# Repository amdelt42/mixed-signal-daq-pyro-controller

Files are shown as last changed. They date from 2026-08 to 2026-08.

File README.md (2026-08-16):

# Mixed-Signal DAQ & Pyrotechnic Control System

This repository contains the [firmware / hardware design] for an STM32-powered data acquisition board.

## Key Features

* **Microcontroller:** STM32 core managing real-time loops, sensor aggregation, and firing logic.
* **Analog Front End:** 
  * Full-bridge strain gauge and Thermocouple measurement signal blocks with dedicated filtering.
  * Local digital temperature sensor for real-time Cold-Junction Compensation (CJC).
  * High-resolution Analog-to-Digital Converter (ADC).
* **Actuation:** Integrated pyrotechnic firing channels.
* **Telemetry & Comms:** High bit-rate CAN FD transceiver for high-bandwidth data output.

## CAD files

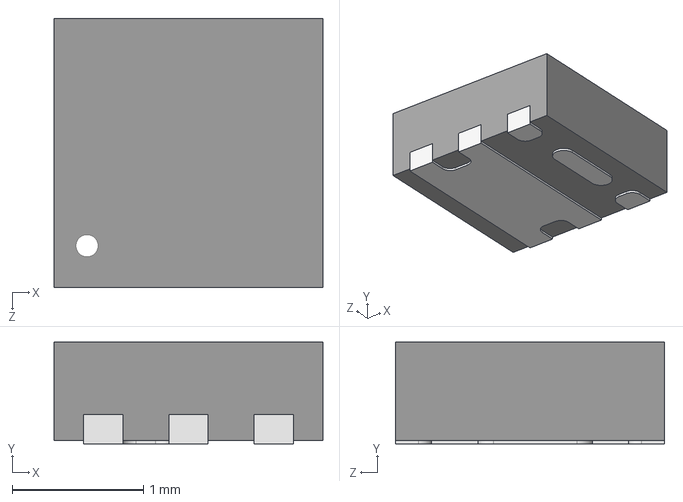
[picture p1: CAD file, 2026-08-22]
GENERAL_STEP_FILES/SQA405EJ-T1_GE3.step
2.05 x 0.775 x 2.05 mm

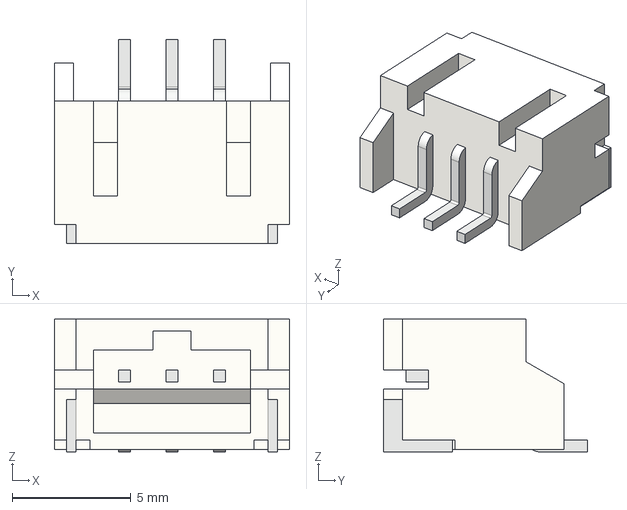
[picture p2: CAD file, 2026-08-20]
JST_PH_SM4_STEP_FILES/JST S3B-PH-SM4-TB.step
9.90 x 8.61 x 5.60 mm

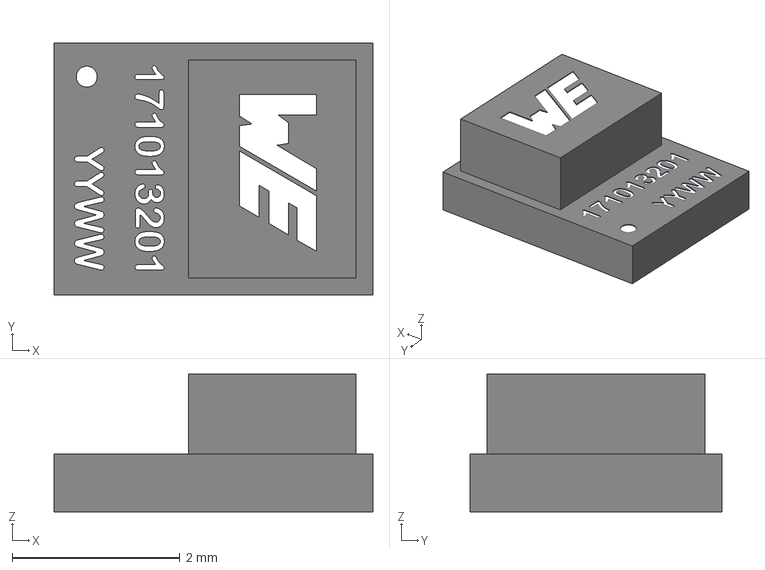
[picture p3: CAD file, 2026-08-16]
MagI3C_171013201/STP_MagIC-VDMM_171013201+(rev1).stp
3.80 x 3.00 x 1.64 mm
contacts
substrate x 2

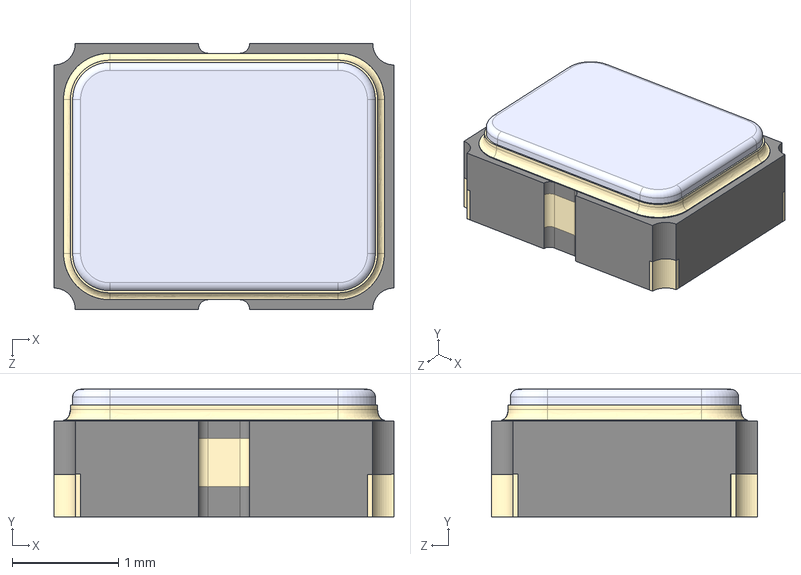
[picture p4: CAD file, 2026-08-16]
SG-8018CE_8.9152M-TJHSA0/SG-8018CE_8.9152M-TJHSA0.step
3.20 x 1.20 x 2.50 mm

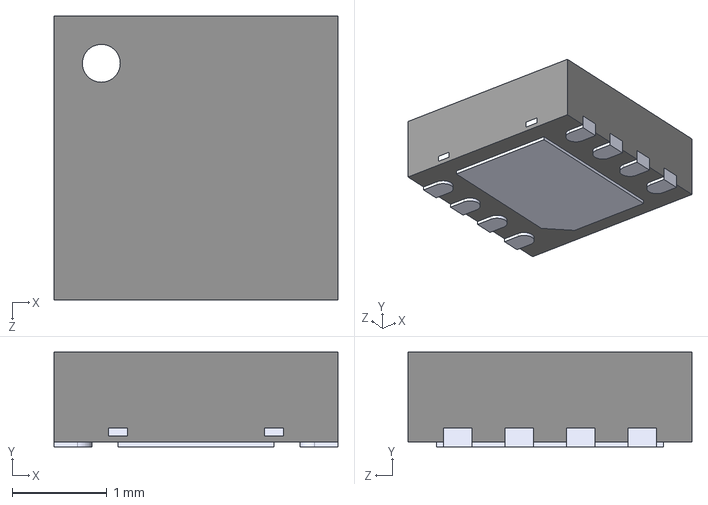
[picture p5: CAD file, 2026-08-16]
TCAN3414DRBR/TCAN3414DRBR.step
3.00 x 1.00 x 3.00 mm

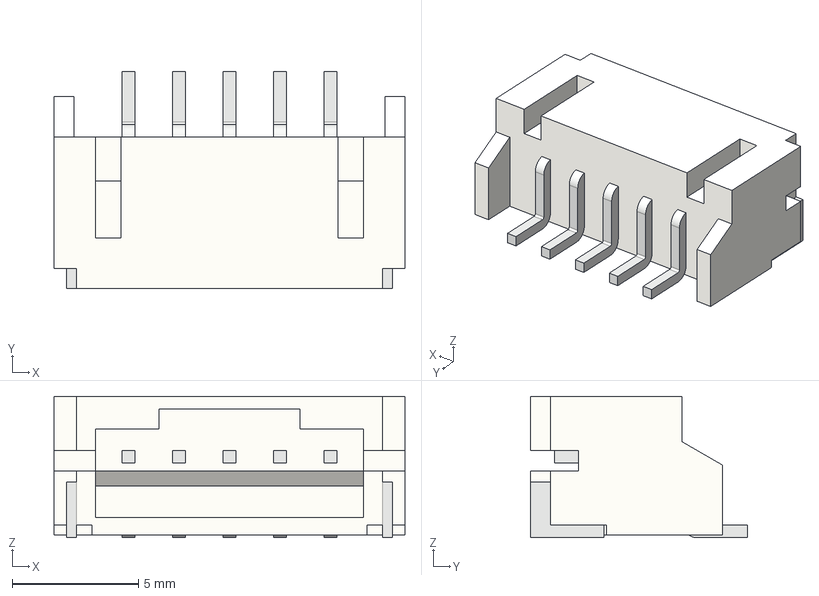
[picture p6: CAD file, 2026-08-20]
JST_PH_SM4_STEP_FILES/JST S5B-PH-SM4-TB.step
13.9 x 8.61 x 5.60 mm

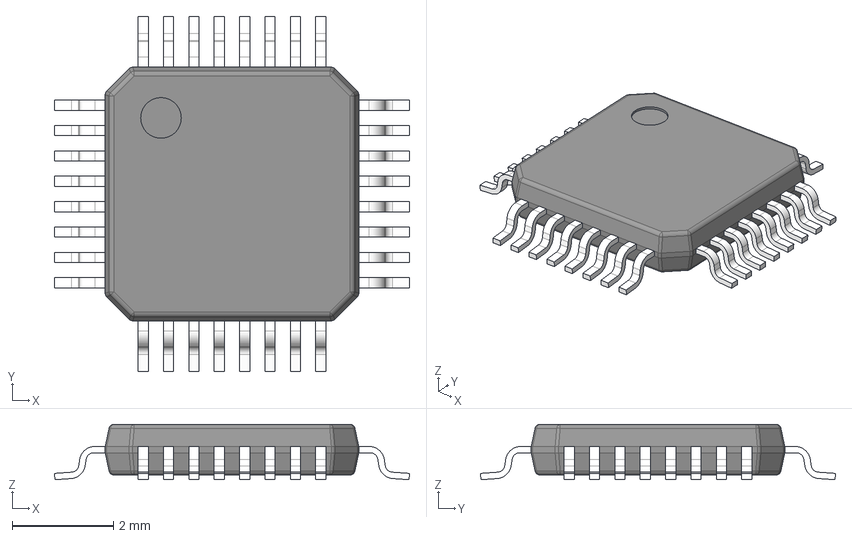
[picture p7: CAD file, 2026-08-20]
GENERAL_STEP_FILES/ADS131M08xPBS.stp
7.00 x 7.00 x 1.09 mm
BODY-TQFP
LEAD-TQFP x 32
PIN1

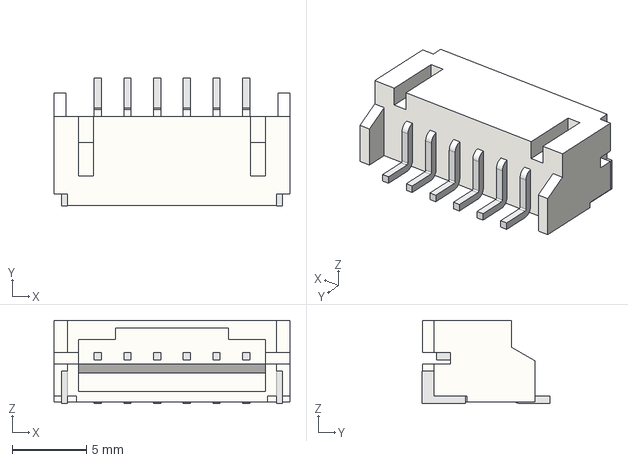
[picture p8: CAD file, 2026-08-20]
JST_PH_SM4_STEP_FILES/JST S6B-PH-SM4-TB.step
15.9 x 8.61 x 5.60 mm

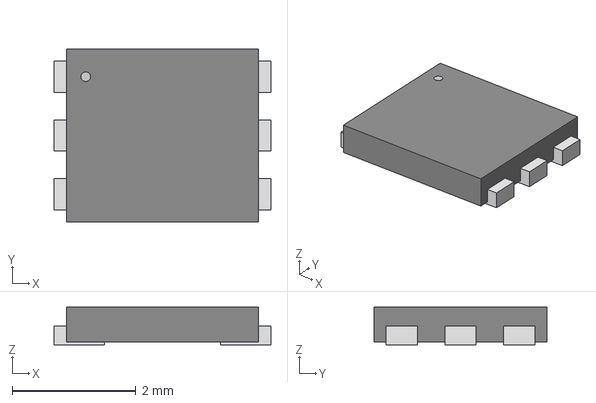
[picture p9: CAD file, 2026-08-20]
GENERAL_STEP_FILES/SMLVN6RGB.step
3.51 x 2.79 x 0.612 mm

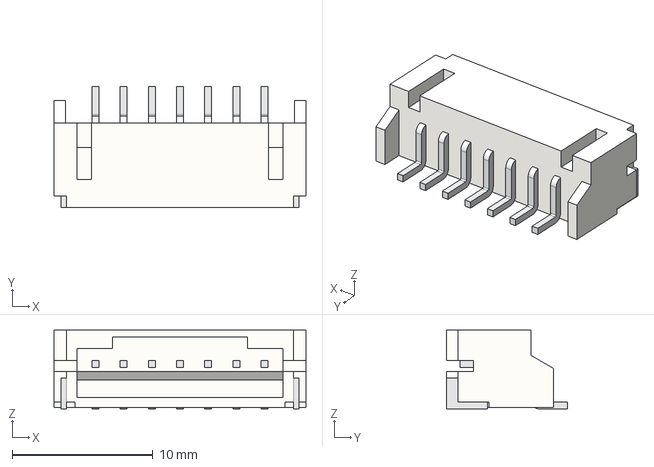
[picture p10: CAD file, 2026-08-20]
JST_PH_SM4_STEP_FILES/JST S7B-PH-SM4-TB.step
17.9 x 8.61 x 5.60 mm

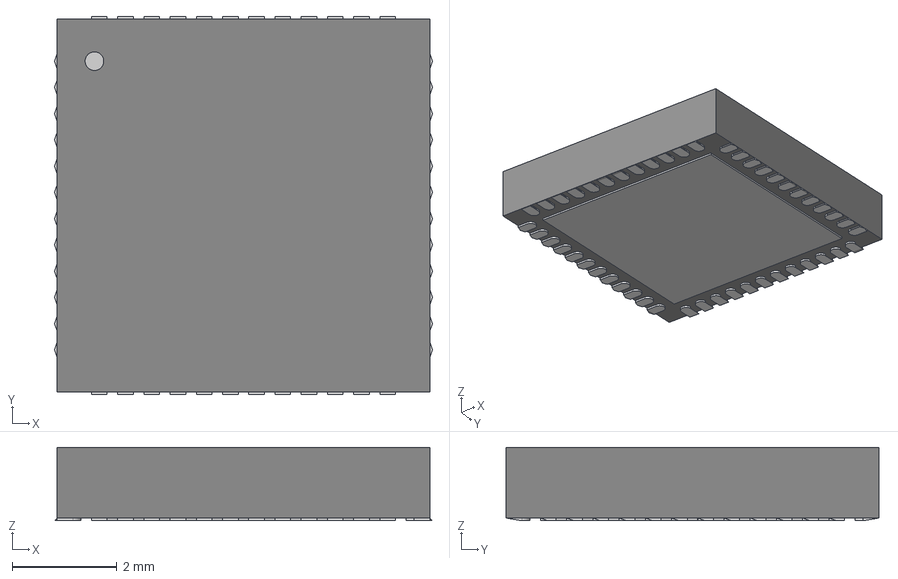
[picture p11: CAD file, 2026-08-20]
GENERAL_STEP_FILES/STM32L552CEUx.step
7.20 x 7.20 x 1.40 mm

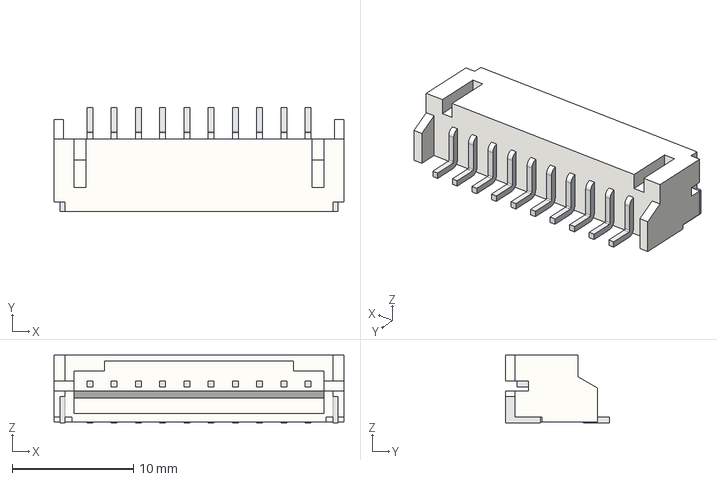
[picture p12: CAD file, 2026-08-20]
JST_PH_SM4_STEP_FILES/JST S10B-PH-SM4-TB.step
23.9 x 8.61 x 5.60 mm

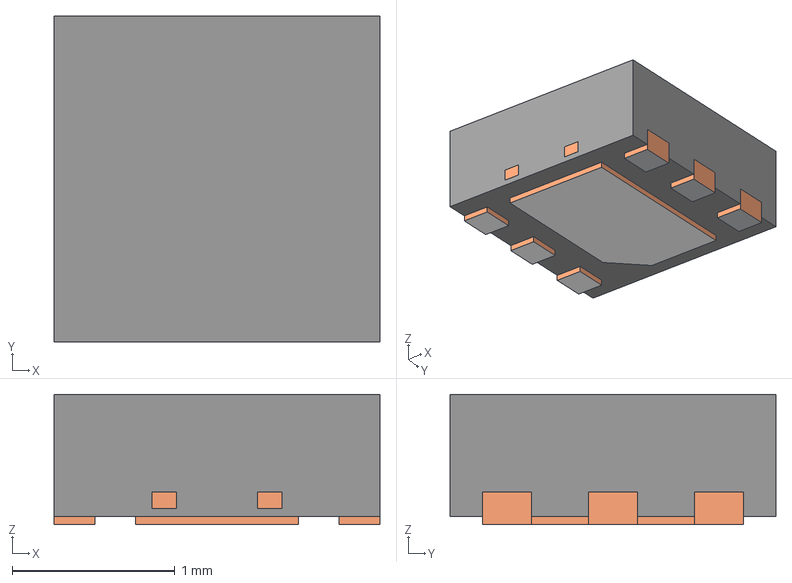
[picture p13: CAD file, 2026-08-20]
GENERAL_STEP_FILES/TMP117xxDRV.stp
2.00 x 2.00 x 0.8 mm
BODY-SON
FRAME-DRV0006A
PIN1-ID

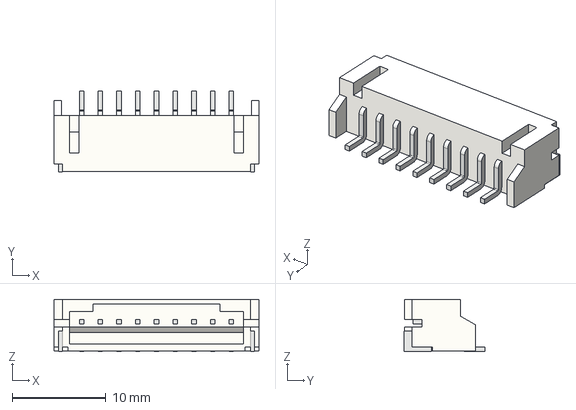
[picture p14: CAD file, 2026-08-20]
JST_PH_SM4_STEP_FILES/JST S9B-PH-SM4-TB.step
21.9 x 8.61 x 5.60 mm

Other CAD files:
JST_PH_SM4_STEP_FILES/JST S4B-PH-SM4-TB.step
JST_PH_SM4_STEP_FILES/JST S2B-PH-SM4-TB.step
JST_PH_SM4_STEP_FILES/JST S8B-PH-SM4-TB.step
GENERAL_STEP_FILES/LM27762.stp

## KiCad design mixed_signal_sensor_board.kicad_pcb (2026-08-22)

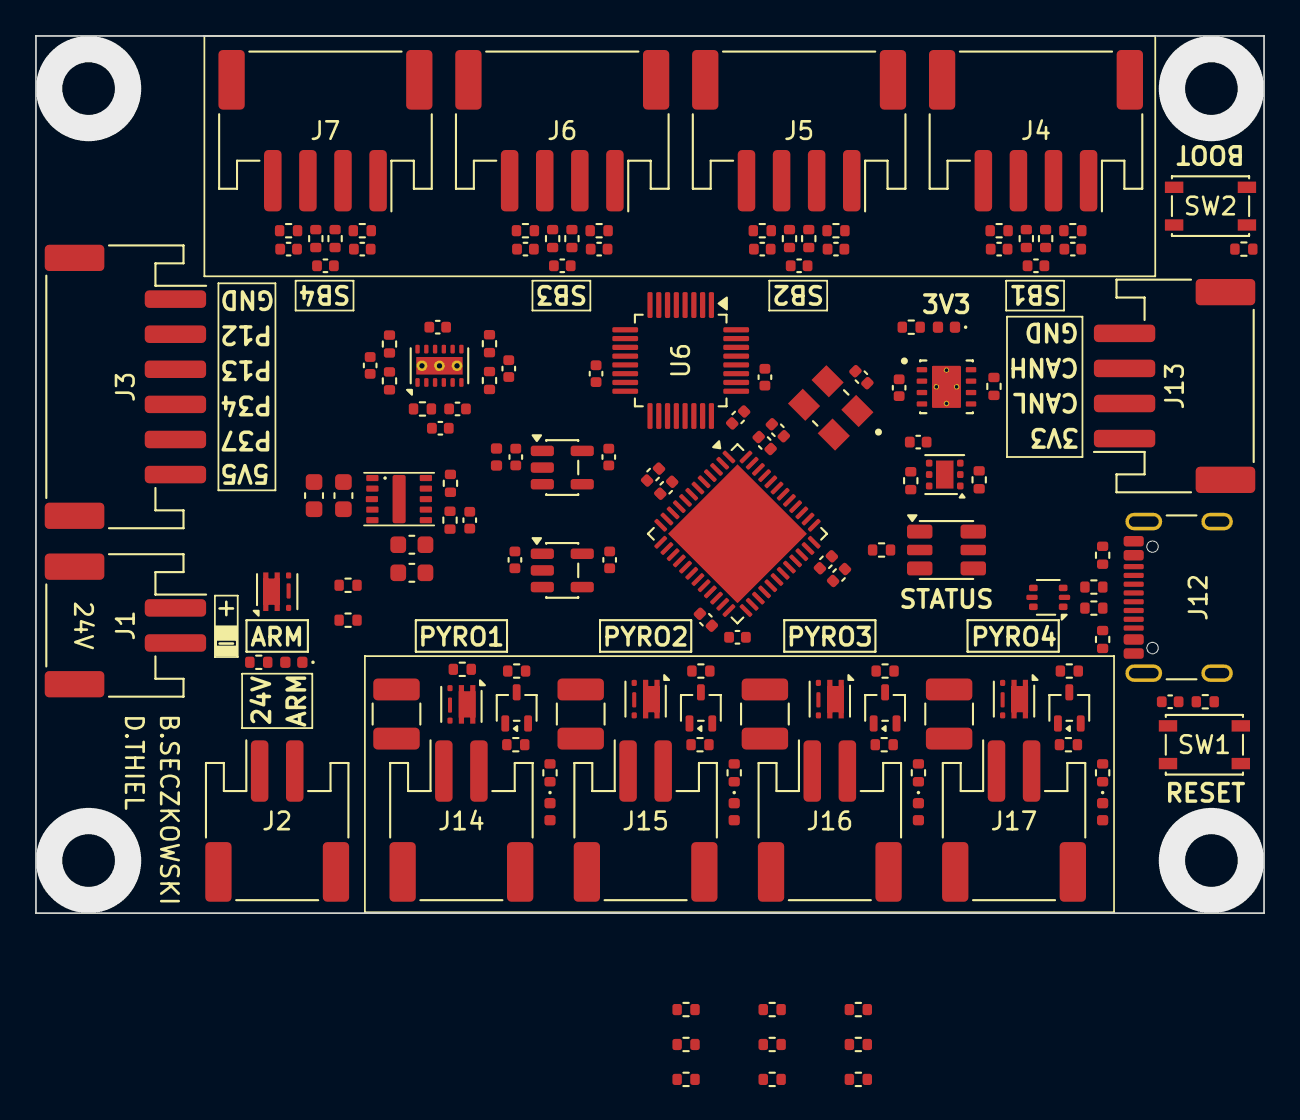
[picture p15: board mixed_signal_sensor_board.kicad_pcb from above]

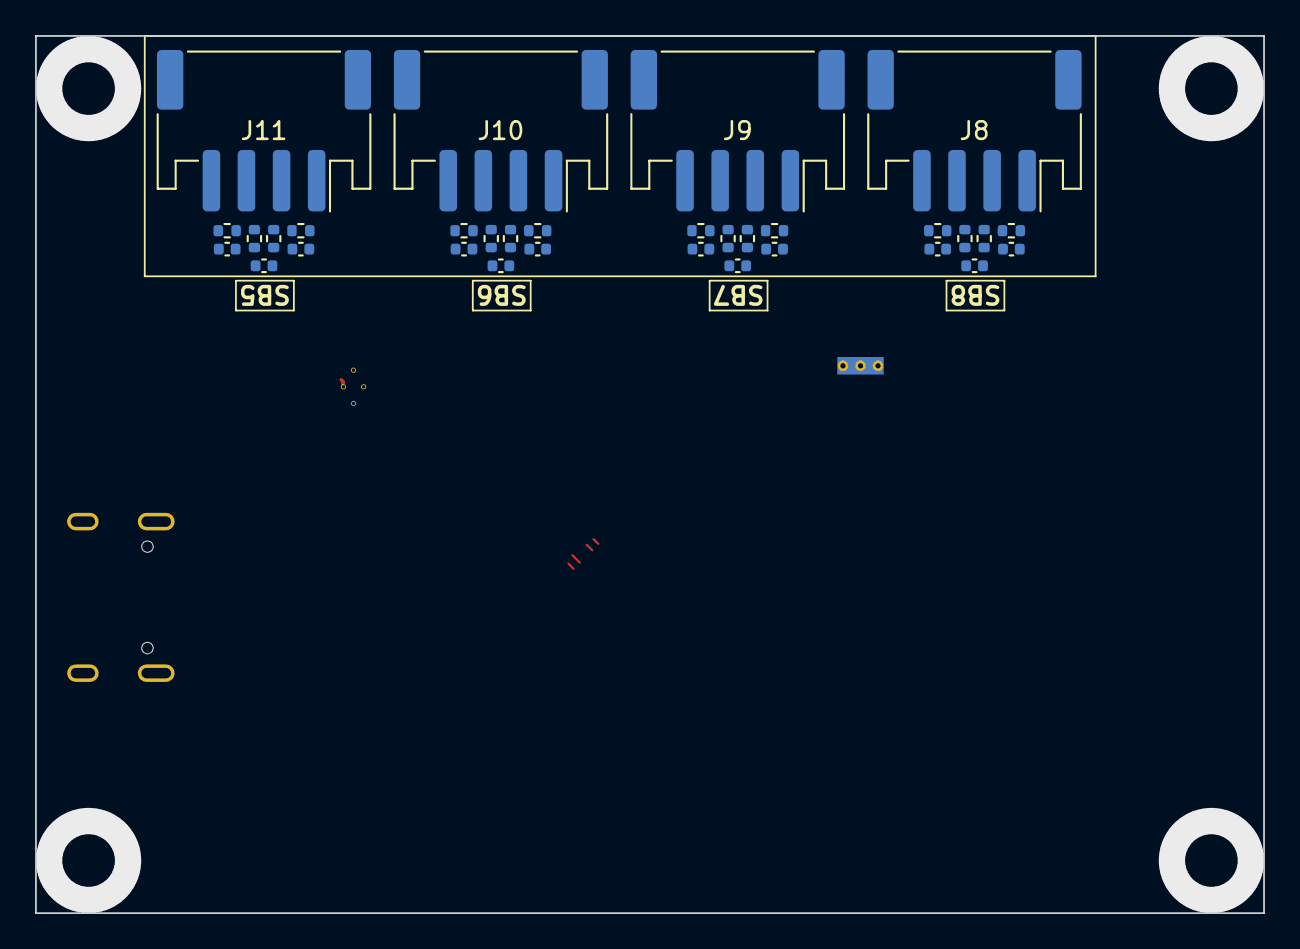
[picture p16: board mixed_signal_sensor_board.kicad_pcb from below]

Board: 4 copper layers, 70.0 x 50.0 mm, 178 parts (32 on the bottom side), 111 nets.

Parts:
C1: 4.7uF; C_0603_1608Metric
C2, C6, C21, C22, C23: 4.7uF; C_0402_1005Metric
C3: 0.47uF; C_0402_1005Metric
C4: 0.47uF; C_0603_1608Metric
C5, C14, C18, C19, C20, C28, C30, C31, C33, C34, C36, C37, C39, C40, C42, C43, C45, C46, C48, C49, C51, C52, C53: 0.1uF; C_0402_1005Metric
C7, C8: 10uF; C_0603_1608Metric
C9, C11: 2.2uF; C_0402_1005Metric
C10: 47pf; C_0402_1005Metric
C12, C13, C15, C16, C17, C24, C26: 1uF; C_0402_1005Metric
C25: 0.22uF; C_0402_1005Metric
C27: 10nF; C_0402_1005Metric
C29, C32, C35, C38, C41, C44, C47, C50: 10nf; C_0402_1005Metric
D1: 24V; D_0402_1005Metric
D2: SMLVN6RGB; LED_ROHM_SMLVN6
D3: LED; LED_0402_1005Metric
D4, D5, D6, D7: 3V; D_0402_1005Metric
F1, F2, F3, F4: MF-USHT050KX-2; Fuse_1210_3225Metric
FB1: 600Ω@100MHz; L_0402_1005Metric
J1: Conn_01x02; JST_PH_S2B-PH-SM4-TB_1x02-1MP_P2.00mm_Horizontal
J2: PYRO_ARM; JST_PH_S2B-PH-SM4-TB_1x02-1MP_P2.00mm_Horizontal
J3: Conn_01x06; JST_PH_S6B-PH-SM4-TB_1x06-1MP_P2.00mm_Horizontal
J4, J5, J6, J7, J8, J9, J10, J11, J13: Conn_01x04; JST_PH_S4B-PH-SM4-TB_1x04-1MP_P2.00mm_Horizontal
J12: USB_C_Receptacle_USB2.0_16P; USB_C_Receptacle_GCT_USB4105-xx-A_16P_TopMnt_Horizontal
J14, J15, J16, J17: PYRO; JST_PH_S2B-PH-SM4-TB_1x02-1MP_P2.00mm_Horizontal
Q2, Q4, Q6, Q8: 2N7002WT1G; SOT-323_SC-70
Q3, Q5, Q7, Q9, Q10: SQA405EJ-T1_GE3; Vishay_PowerPAK_SC70-6L_Single
R1, R5, R6, R9, R10, R17, R18, R21, R22, R25, R26, R29, R30, R33, R34, R37, R38, R41, R42, R45, R46: 10K; R_0402_1005Metric
R2, R7: 100K; R_0402_1005Metric
R3, R4: 5K; R_0402_1005Metric
R8: 16K9; R_0402_1005Metric
R11, R14, R51: 120R; R_0402_1005Metric
R12, R13: 4K7; R_0402_1005Metric
R15, R16, R19, R20, R23, R24, R27, R28, R31, R32, R35, R36, R39, R40, R43, R44: 1MΩ; R_0402_1005Metric
R47, R48: 5K1; R_0402_1005Metric
R49, R50: 22R; R_0402_1005Metric
R52, R54, R58, R60, R64, R66, R70, R72: 10k; R_0402_1005Metric
R53, R55, R59, R61, R65, R67, R71, R73: 1k; R_0402_1005Metric
R56, R57, R62, R63, R68, R69, R74, R75: 50k; R_0402_1005Metric
SW1, SW2: SW_Push; SW_SPST_PTS810
U1: TMP117xxDRV; WSON-6-1EP_2x2mm_P0.65mm_EP1x1.6mm
U2: LM27762; WSON-12-1EP_3x2mm_P0.5mm_EP1x2.65_ThermalVias
U3: MagI3C_171013201
U4, U5: TPS7A20xxxDBV; SOT-23-5
U6: ADS131M08xPBS; TQFP-32_5x5mm_P0.5mm
U7: STM32L552CEUx; QFN-48-1EP_7x7mm_P0.5mm_EP5.6x5.6mm
U8: USBLC6-2P6; SOT-666
U9: TCAN3414DRBR; XCVR_TCAN3414DRBR
Y1: SG-8018CE_8.192M-TJHSA; OSC_SG-8018CE_8.9152M-TJHSA0

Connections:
+3V3: C5.1, C16.1, C18.2, C19.2, C20.2, C21.2, C22.2, C23.2, C24.1, C28.2, C53.1, J13.1, R3.2, R4.2, R12.1, R14.1, SW2.1, U1.5 (V+), U5.5 (OUT), U6.26 (DVDD), U7.1 (VBAT), U7.24 (VDD), U7.36 (VDD), U7.48 (VDD), U9.3 (VCC), Y1.1 (~ST), Y1.4 (VCC)
+3V3A: C15.1, C17.1, C26.2, C27.2, R15.1, R19.1, R23.1, R27.1, R31.1, R35.1, R39.1, R43.1, U4.5 (OUT), U6.15 (AVDD), U7.9 (VDDA)
+5V: C9.1, J4.1, J5.1, J6.1, J7.1, J8.1, J9.1, J10.1, J11.1, R5.1, U2.11 (OUT+)
+5V5: C2.2, C7.2, C8.2, C10.2, C13.2, FB1.2, J3.6, R1.1, R7.1, U2.3 (VIN), U2.8 (EN-), U2.12 (EN+), U3.6 (VOUT), U5.1 (IN), U5.3 (EN)
+24V: C1.2, C4.2, D1.1 (K), J2.1, Q10.4 (S), R56.2, R62.2, R68.2, R74.2, U3.3 (VIN), U3.4 (EN)
-5V: C11.1, J4.4, J5.4, J6.4, J7.4, J8.4, J9.4, J10.4, J11.4, R9.1, U2.6 (OUT-)
/ADS_DRDY: U6.18 (~DRDY), U7.2 (PC13)
/ADS_SYNC/RESET: U6.16 (~SYNC/~RESET), U7.3 (PC14)
/BOOT0: R13.1, SW2.2, U7.44 (PH3)
/CAN/CAN_H: J13.3, R51.2, U9.7 (CANH)
/CAN/CAN_L: J13.2, R51.1, U9.6 (CANL)
/CAN_RX: U7.45 (PB8), U9.4 (RXD)
/CAN_TX: U7.46 (PB9), U9.1 (TXD)
/CLK_IN: U6.23 (XTAL1/CLKIN), Y1.3 (OUT)
/CS: U6.17 (~CS), U7.14 (PA4)
/FB: C10.1, R7.2, R8.1, U3.7 (FB)
/FB+: R5.2, R6.1, U2.2 (FB+)
/FB-: R9.2, R10.1, U2.7 (FB-)
/LEDB: D2.1 (BA), U7.41 (PB5)
/LEDG: D2.3 (GA), U7.39 (PB3)
/LEDR: R11.1, U7.40 (PB4)
/MISO: U6.20 (DOUT), U7.16 (PA6)
/MOSI: U6.21 (DIN), U7.17 (PA7)
/NRST: C14.1, R12.2, SW1.2, U7.7 (NRST)
/PGOOD: R1.2, U2.1 (PGOOD), U7.38 (PA15)
/PYRO1_FAULT: D4.1 (K), R57.2, U7.19 (PB1)
/PYRO1_SIGNAL: R52.2, R53.1, U7.18 (PB0)
/PYRO2_FAULT: D5.1 (K), R63.2, U7.21 (PB10)
/PYRO2_SIGNAL: R58.2, R59.1, U7.20 (PB2)
/PYRO3_FAULT: D6.1 (K), R69.2, U7.28 (PB15)
/PYRO3_SIGNAL: R64.2, R65.1, U7.29 (PA8)
/PYRO4_FAULT: D7.1 (K), R75.2, U7.30 (PA9)
/PYRO4_SIGNAL: R70.2, R71.1, U7.31 (PA10)
/SB1/AOUT_N: C29.2, C31.2, R18.2, U6.2 (AIN2N)
/SB1/AOUT_P: C29.1, C30.1, R17.2, U6.1 (AIN2P)
/SB1/SIGNAL_N: J4.3, R16.1, R18.1
/SB1/SIGNAL_P: J4.2, R15.2, R17.1
/SB2/AOUT_N: C32.2, C34.2, R22.2, U6.3 (AIN3N)
/SB2/AOUT_P: C32.1, C33.1, R21.2, U6.4 (AIN3P)
/SB2/SIGNAL_N: J5.3, R20.1, R22.1
/SB2/SIGNAL_P: J5.2, R19.2, R21.1
/SB3/AOUT_N: C35.2, C37.2, R26.2, U6.6 (AIN4N)
/SB3/AOUT_P: C35.1, C36.1, R25.2, U6.5 (AIN4P)
/SB3/SIGNAL_N: J6.3, R24.1, R26.1
/SB3/SIGNAL_P: J6.2, R23.2, R25.1
/SB4/AOUT_N: C38.2, C40.2, R30.2, U6.7 (AIN5N)
/SB4/AOUT_P: C38.1, C39.1, R29.2, U6.8 (AIN5P)
/SB4/SIGNAL_N: J7.3, R28.1, R30.1
/SB4/SIGNAL_P: J7.2, R27.2, R29.1
/SB5/AOUT_N: C41.2, C43.2, R34.2, U6.11 (AIN7N)
/SB5/AOUT_P: C41.1, C42.1, R33.2, U6.12 (AIN7P)
/SB5/SIGNAL_N: J8.3, R32.1, R34.1
/SB5/SIGNAL_P: J8.2, R31.2, R33.1
/SB6/AOUT_N: C44.2, C46.2, R38.2, U6.10 (AIN6N)
/SB6/AOUT_P: C44.1, C45.1, R37.2, U6.9 (AIN6P)
/SB6/SIGNAL_N: J9.3, R36.1, R38.1
/SB6/SIGNAL_P: J9.2, R35.2, R37.1
/SB7/AOUT_N: C47.2, C49.2, R42.2, U6.31 (AIN1N)
/SB7/AOUT_P: C47.1, C48.1, R41.2, U6.32 (AIN1P)
/SB7/SIGNAL_N: J10.3, R40.1, R42.1
/SB7/SIGNAL_P: J10.2, R39.2, R41.1
/SB8/AOUT_N: C50.2, C52.2, R46.2, U6.30 (AIN0N)
/SB8/AOUT_P: C50.1, C51.1, R45.2, U6.29 (AIN0P)
/SB8/SIGNAL_N: J11.3, R44.1, R46.1
/SB8/SIGNAL_P: J11.2, R43.2, R45.1
/SCL: R4.1, U1.1 (SCL), U7.42 (PB6)
/SCLK: U6.19 (SCLK), U7.15 (PA5)
/SDA: R3.1, U1.6 (SDA), U7.43 (PB7)
/SWCLK: J3.5, U7.37 (PA14)
/SWDIO: J3.4, U7.34 (PA13)
/USART2_RX: J3.3, U7.13 (PA3)
/USART2_TX: J3.2, U7.12 (PA2)
/USB/DN: J12.A7 (D-), J12.B7 (D-), R49.1
/USB/DP: J12.A6 (D+), J12.B6 (D+), R50.1
/USB_N: U7.32 (PA11), U8.6 (I/O1)
/USB_P: U7.33 (PA12), U8.4 (I/O2)
ARM: J2.2, Q3.1 (D), Q5.1 (D), Q7.1 (D), Q9.1 (D), R54.1, R60.1, R66.1, R72.1
GND: C1.1, C2.1, C4.1, C5.2, C6.2, C7.1, C8.1, C9.2, C11.2, C12.1, C13.1, C14.2, C15.2, C16.2, C17.2, C18.1, C19.1, C20.1, C21.1, C22.1, C23.1, C24.2, C25.2, C26.1, C27.1, C28.1, C30.2, C31.1, C33.2, C34.1, C36.2, C37.1, C39.2, C40.1, C42.2, C43.1, C45.2, C46.1, C48.2, C49.1, C51.2, C52.1, C53.2, D2.4 (GK), D2.5 (RK), D2.6 (BK), D3.1 (K), D4.2 (A), D5.2 (A), D6.2 (A), D7.2 (A), J1.2, J3.1, J12.A1 (GND), J12.A12 (GND), J12.B1 (GND), J12.B12 (GND), J13.4, J14.2, J15.2, J16.2, J17.2, Q2.2 (S), Q4.2 (S), Q6.2 (S), Q8.2 (S), R2.2, R6.2, R8.2, R10.2, R13.2, R16.2, R20.2, R24.2, R28.2, R32.2, R36.2, R40.2, R44.2, R47.1, R48.1, R52.1, R58.1, R64.1, R70.1, SW1.1, U1.2 (GND), U1.4 (ADD0), U2.4 (GND), U2.13 (PAD), U3.1 (GND), U4.2 (GND), U5.2 (GND), U6.13 (AGND), U6.25 (DGND), U6.27 (AGND), U6.28 (AGND), U7.8 (VSSA), U7.23 (VSS), U7.35 (VSS), U7.47 (VSS), U7.49 (VSS), U8.2 (GND), U9.2 (GND), U9.5 (SHDN), U9.8 (STB), U9.9 (EXP), Y1.2 (GND)
unnamed: D1.2 (A), Q10.3 (G), R2.1
unnamed: D2.2 (RA), R11.2
unnamed: D3.2 (A), R14.2
unnamed: J1.1, Q10.1 (D)
unnamed: J12.A5 (CC1), R48.2
unnamed: J12.B5 (CC2), R47.2
unnamed: F1.2, J14.1, R56.1, R57.1
unnamed: F2.2, J15.1, R62.1, R63.1
unnamed: F3.2, J16.1, R68.1, R69.1
unnamed: F4.2, J17.1, R74.1, R75.1
unnamed: Q2.3 (D), R54.2, R55.1
unnamed: Q2.1 (G), R53.2
unnamed: Q3.3 (G), R55.2
unnamed: F1.1, Q3.4 (S)
unnamed: Q4.3 (D), R60.2, R61.1
unnamed: Q4.1 (G), R59.2
unnamed: Q5.3 (G), R61.2
unnamed: F2.1, Q5.4 (S)
unnamed: Q6.3 (D), R66.2, R67.1
unnamed: Q6.1 (G), R65.2
unnamed: Q7.3 (G), R67.2
unnamed: F3.1, Q7.4 (S)
unnamed: Q8.3 (D), R72.2, R73.1
unnamed: Q8.1 (G), R71.2
unnamed: Q9.3 (G), R73.2
unnamed: F4.1, Q9.4 (S)
unnamed: R49.2, U8.1 (I/O1)
unnamed: R50.2, U8.3 (I/O2)
unnamed: C3.1, U2.10 (C+)
unnamed: C3.2, U2.9 (C-)
unnamed: C6.1, U2.5 (CP)
unnamed: C12.2, FB1.1, U4.1 (IN), U4.3 (EN)
unnamed: C25.1, U6.24 (CAP)

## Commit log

2026-08-19 24V Regulator, Pyro Igniter Circuit
    [can.kicad_sch, mixed_signal_sensor_board.kicad_pcb, mixed_signal_sensor_board.kicad_sch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]
2026-08-20 Pyro fault detection, Decoupling Caps STM32, Initial PCB Layout
    [can.kicad_sch, mixed_signal_sensor_board.kicad_pcb, mixed_signal_sensor_board.kicad_sch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]
2026-08-20 Finished first rough initial layout
    [mixed_signal_sensor_board.kicad_pcb, mixed_signal_sensor_board.kicad_sch]
2026-08-20 Step files, SMD connectors, reduced size
    [ADS131M08xPBS.stp, CSD17571Q2.stp, JST S10B-PH-SM4-TB.step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]
2026-08-20 Delvin protection, USB ESD protection, 02x06 pin socket
    [can.kicad_sch, mixed_signal_sensor_board.kicad_pcb, mixed_signal_sensor_board.kicad_sch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]
2026-08-21 replaced signal blocks, shortening board, adding precise positioning
    [can.kicad_sch, mixed_signal_sensor_board.kicad_pcb, mixed_signal_sensor_board.kicad_sch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]
2026-08-21 Compact board, Artistic Freedom
    [mixed_signal_sensor_board.kicad_pcb, mixed_signal_sensor_board.kicad_sch]
2026-08-21 Artistic Freedom
    [mixed_signal_sensor_board.kicad_pcb]
2026-08-21 removed SPI, I2C, compacting pyro channels, new pyro schematic
    [mixed_signal_sensor_board.kicad_pcb, mixed_signal_sensor_board.kicad_sch, pyro.kicad_sch]
2026-08-22 New pyro layout, SWDIO, SWCLK, USART2 TX RX, 70x50mm board
    [mixed_signal_sensor_board.kicad_pcb, mixed_signal_sensor_board.kicad_sch, pyro.kicad_sch]
2026-08-22 PYRO done, schematic structure/convention update, pyro and reverse polarity components selected
    [CSD17571Q2.stp, SQA405EJ-T1_GE3.step, adc.kicad_sch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]
